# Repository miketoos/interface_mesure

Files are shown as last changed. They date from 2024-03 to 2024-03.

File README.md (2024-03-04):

# Projet d'Interface de Mesure pour Calculateur de Voiture

Ce projet vise à développer une interface de mesure entre un calculateur de voiture et l'être humain. L'objectif principal est de gérer jusqu'à 4 signaux d'injection pour une première carte, tandis que pour une deuxième carte, l'interface doit gérer les signaux de PMH (Point Mort Haut), l'écart en degré sur l'avance à l'allumage, le temps de conduction et la valeur d'accélération.

## Configuration du Projet
### Matériel Requis
- Accès à un calculateur de voiture (Clio 2)
- Carte électronique Arduino
- Sonde de programmation JLink
- Port USB B pour le téléversement du code

### Installation des Pilotes
1. Ajoutez la carte via le lien : [https://www.mattairtech.com/software/arduino/package_MattairTech_index.json](https://www.mattairtech.com/software/arduino/package_MattairTech_index.json)
2. Installez la carte via Outils / Type de carte / Gestionnaire de carte
3. Recherchez "MattairTech SAMD|L|C core for Arduino" et installez-le

### Programmation de la Carte
1. Sélectionnez la carte dans Arduino : Outils / Type de carte / "MattairTech MT-D21E(rev B)"
2. Sélectionnez l'oscillateur interne et le port de communication

### Blink (Test de Programmation)
- Assurez-vous que la carte est détectée dans le logiciel Arduino
- Chargez le programme Blink pour tester la programmation

## Fonctionnalités Principales
### Injection
- Contrôle jusqu'à 4 signaux d'injection pour la première carte (à compléter)

### Régime Moteur
- Mesure et affichage du régime moteur en tr/min

### Avance à l'Allumage
- Calcul et contrôle de l'avance à l'allumage en degrés

### Temps de Conduction
- Mesure du temps de conduction du moteur

### Accélération
- Calcul de l'accélération en fonction du régime moteur

## Production et Commande
- Les fichiers Gerber dans la section hardware permettent la production de cartes électroniques. Les entreprises peuvent être contactées en fournissant ces fichiers.
- Les fichiers de la section mécanique facilitent la production de boîtiers pour les cartes électroniques.

## Téléversement du Code
- Les codes nécessaires sont disponibles dans la section software.
- Utilisez une connectique en port USB B pour téléverser le code sur la carte.

## Contribuer
1. Fork le projet
2. Créez une branche pour votre fonctionnalité (`git checkout -b fonctionnalite/nouvelle-fonction`)
3. Committez vos changements (`git commit -m 'Ajout de nouvelle fonctionnalité'`)
4. Push vers la branche (`git push origin fonctionnalite/nouvelle-fonction`)
5. Créez une Pull Request

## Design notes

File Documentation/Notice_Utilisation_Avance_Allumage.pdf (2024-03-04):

# Notice Utilisation Carte Retard Allumage CIFAM

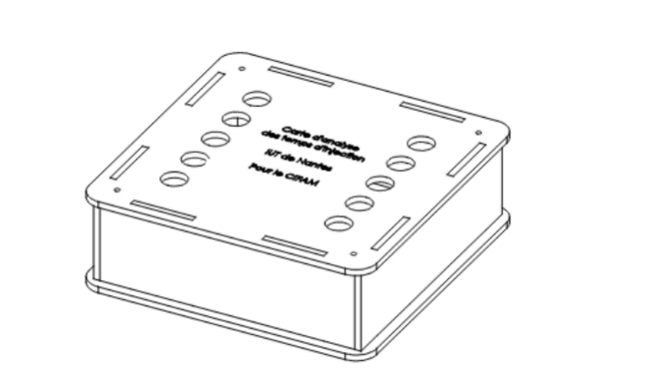
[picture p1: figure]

La carte Retard Allumage CIFAM est une carte qui permet de réaliser plusieurs calculs : Le Régime moteur ( Tr / min ), l’avance à l’allumage ( ° ), la durée de la charge de la bobine ou Temps de conduction ( ms ) et le calcul de l’accélération ( Tr / min²). Le gain de conversion est réglé en interne ( Tableau de conversion en annexe ) pour limiter le nombre de composants extérieurs. Les entrées et les sorties sont référencées à la masse. La consommation maximale est de 2.5W avec une alimentation de 5V, ce qui fait que cette carte est idéale pour un branchement sur batterie.

## Branchement :

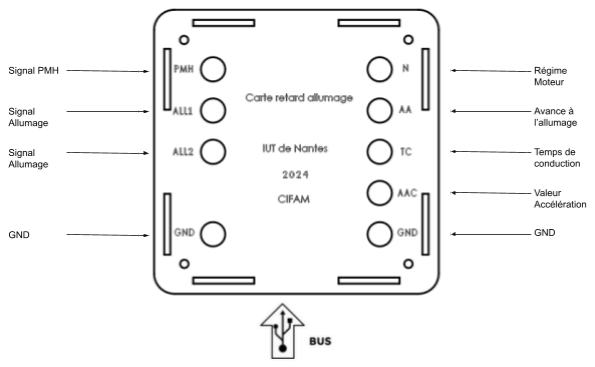
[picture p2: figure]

## Renseignement Techniques

Tension d’entrée ( Vbus ) | 5V
Courant d'entrée Max ( Ibus ) | 500 mA
Puissance Max ( P ) | 2,5 W
Tension d’entrée ( Vin ) | 0V - 5V
Tension de sortie ( Vout ) | 0V - 4.096V

## Description

FR
La carte électronique doit être alimentée sous 5V en courant continu (DC) sur le connecteur USB-B. Les dispositifs d’entrées sont en 0-5V; Les dispositifs de sortie sont en 0 - 4.096V, l’ensemble des dispositifs ne doit pas dépasser 2.5W. Les dispositifs d’entrée et de sortie sont référencés sur une masse commune (plan de masse). La carte est munie d’un bouton RESET qui permet de relancer le microcontrôleur de la carte. Une Led Rouge permet de savoir si la carte est sous tension. Une Led Verte permet de savoir si le microcontrôleur fonctionne.

Attention: Un branchement des dispositifs d’entrée avant la tension d’alimentation peut le rendre défectueux voire inutilisable

EN
The electronic board must be supplied with 5V direct current (DC) via the USB-B connector. Input devices are 0-5V; output devices are 0 - 4.096V, all devices must not exceed 2.5W. Input and output devices are referenced to a common ground (ground plane). The board is fitted with a RESET button to restart the board's microcontroller. A red LED indicates that the board is powered up. A green LED indicates that the microcontroller is working.

Caution: Connecting input devices before the supply voltage is applied may render them defective or even unusable.

## Tableau de conversion :

Sortie | Régime Moteur | Avance Allumage | Temps de conduction | Accélération
Unité | Tr / min | ° | ms | Tr / min
Echelle | 1V -> 1000 Tr / min | 68 mV - > 1° | 1V -> 1ms | 1V -> 1000 Tr /min² La valeur nulle est initialisée à 1V

## Remarque :

La carte ne peut sortir que 4.096V en sortie en raison du Convertisseur Analogique Numérique ( CAN ) situé sur le circuit, En fonction des valeurs souhaitées la modification en interne au niveau de programmation est possible afin de modifier les valeurs de sortie. Pour une modification du gain, il faudra passer par la modification du programme, et modifier les variables Gain_OutX. ( X étant le numéro de la sortie ).

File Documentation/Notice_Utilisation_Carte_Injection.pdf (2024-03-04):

# Notice Utilisation Carte Injection CIFAM

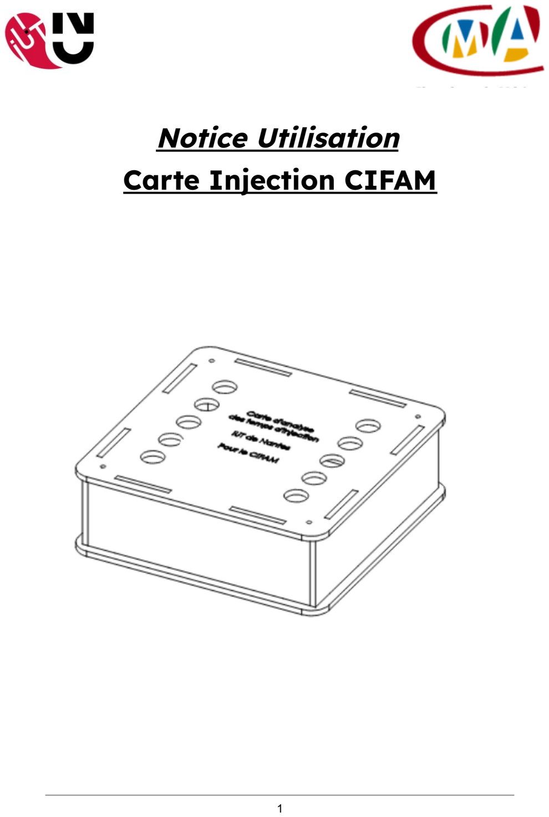
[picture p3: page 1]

La carte injection CIFAM est une carte qui permet de calculer le temps d’injection dans un moteur. Le gain de conversion est réglé en interne ( 1 ms -> 0,5V ) pour limiter le nombre de composants extérieurs. Les entrées et les sorties sont référencées à la masse. La consommation maximale est de 2.5W avec une alimentation de 5V, ce qui fait que cette carte est idéale pour un branchement sur batterie.

## Pin configuration

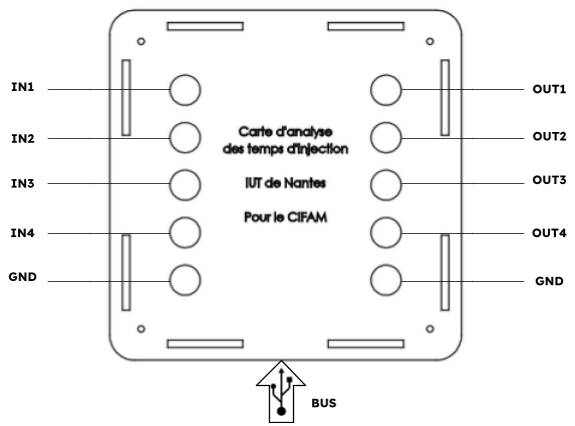
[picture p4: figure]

Renseignements Techniques

Tension d’entrée ( Vbus ) | 5V
Courant d'entrée Max ( Ibus ) | 500 mA
Puissance Max ( P ) | 2,5 W
Tension d’entrée ( Vin ) | 0V - 12V
Tension de sortie ( Vout ) | 0V - 4.96V

Masse commune ( GND )

## Description :

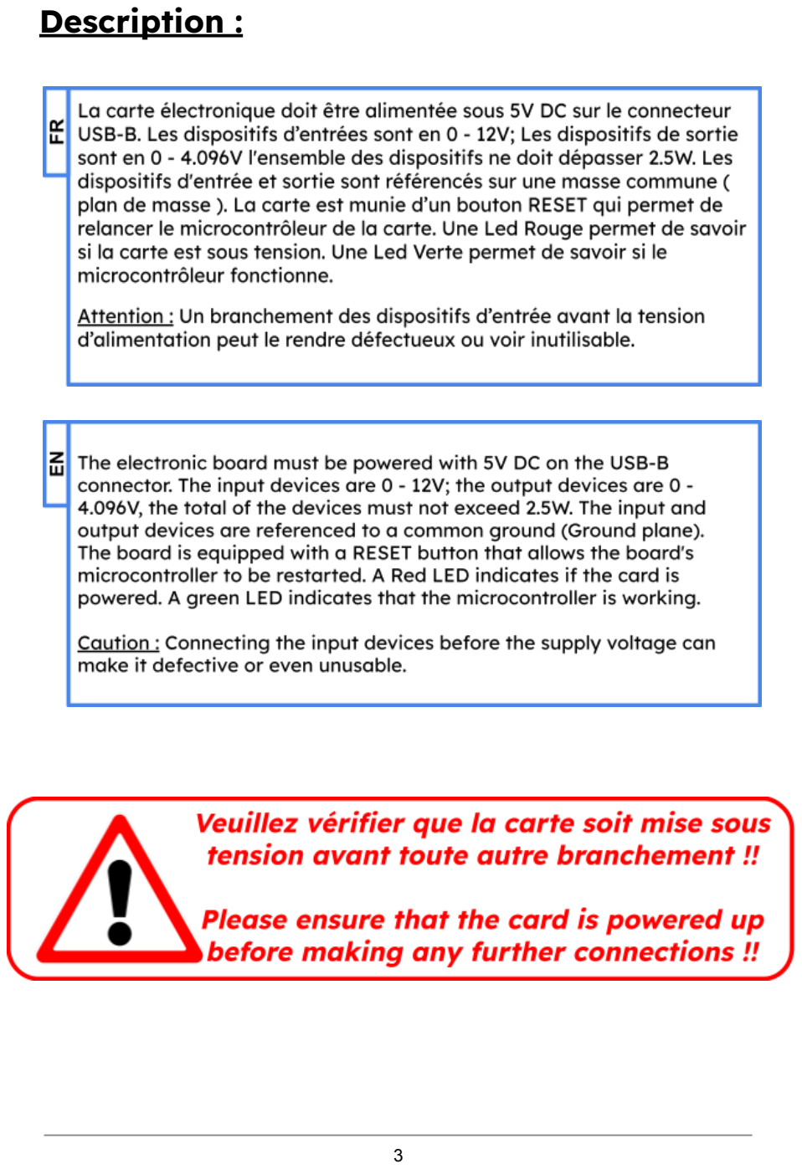
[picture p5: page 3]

## Application :

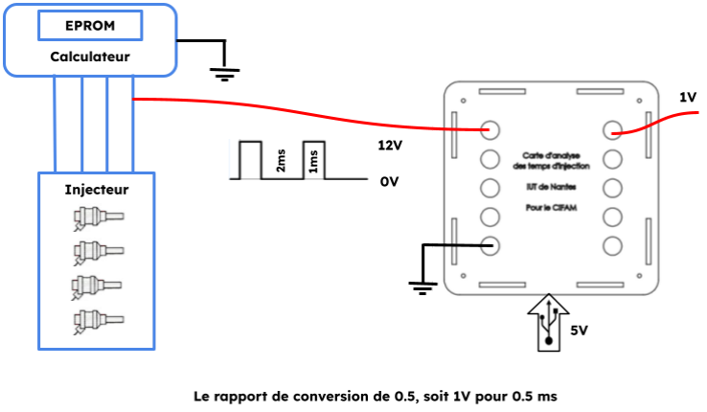
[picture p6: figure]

## Remarque :

La carte ne peut sortir que 4.096V en sortie en raison du Convertisseur Analogique Numérique ( CAN ) situé sur le circuit, soit la carte ne peut calculer au-delà de 8,192ms de temps d’injection. Pour une modification du gain, il faudra passer par la modification du programme, et modifier la variable GAIN.

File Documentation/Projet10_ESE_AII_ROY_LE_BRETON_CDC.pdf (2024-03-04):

RAPPORT SAE 6

# Interface de mesure pour calculateur automobile

Auteurs : Cyrian LE BRETON & Gaëtan ROY

Référence | Compte-rendu SAE 6
Titre du projet | Étude et réalisation du projet Interface de mesure
Type de projet | Électronique et informatique
Période du projet | 15/01/2024 - 19/01/2024
Nature du rapport | Livrable 1

## Sommaire

## État d’avancement du projet

L’intitulé de notre projet est “interface de mesure”, il consiste sommairement à rendre intelligible des signaux que génère un calculateur du moteur d’une voiture, pour être interprétable par un humain. Pour entrer plus dans le détail, il faut savoir que notre projet a été commencé lors de la SAE5 en septembre 2023 - décembre 2024, mais la première approche de ce projet date de 2017. Nous reprenons ainsi les cartes de mesures réalisées, voici un aperçu de la carte de retard à l'allumage.

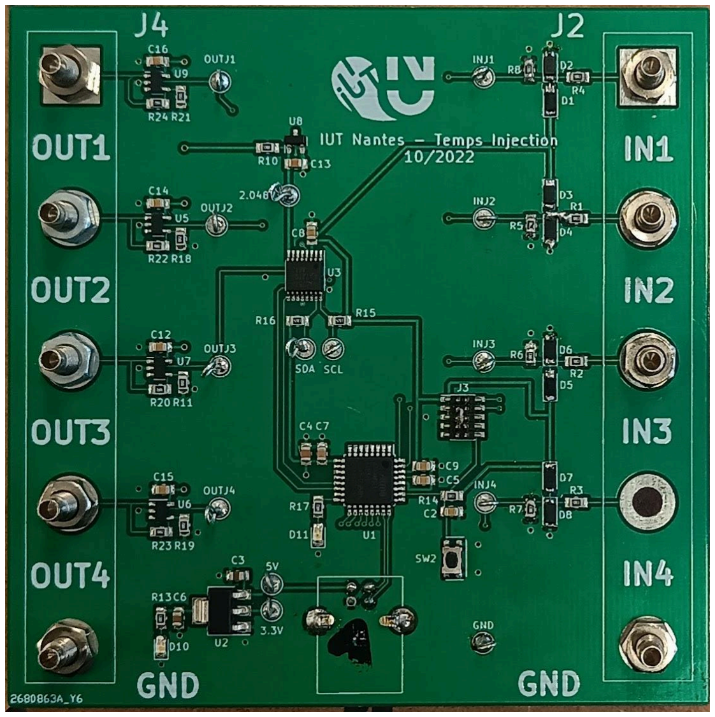
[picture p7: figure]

Puis de traiter les signaux dans la carte grâce à la programmation d’un microcontrôleur qui est une sorte de petit ordinateur intégré qui gère et contrôle les signaux électriques dans un dispositif électronique, grâce à un programme préalablement chargé. À la suite de ce traitement, nous sortons un certain niveau de tension qui donne des informations beaucoup plus claires pour l’utilisateur, lui évitant de faire des calculs, qui sont en fait assurés par le microcontrôleur, par exemple, on va faire en sorte que si on calcule que le moteur tourne actuellement à 1000 tours/min, on sorte 1V.

Donc comme rappelé, le projet débuté depuis 2017, depuis lors, la carte électronique a été désigné et produire, a été réalisée un boitier pour sécuriser l’ensemble et donner un aspect présentable, car l’objectif final est de “livrer” ce produit au CIFAM (CFA de la chambre de Métiers et de L’artisanat de Loire-Atlantique) pour leurs étudiants en mécanique. À ce titre, nous travaillons avec un de leur enseignant, Mr. Fourmy pour premièrement bien définir le cahier des charges et avoir un interlocuteur pour tester notre solution sur place, car c’est bien là-bas que nos cartes vont servir.

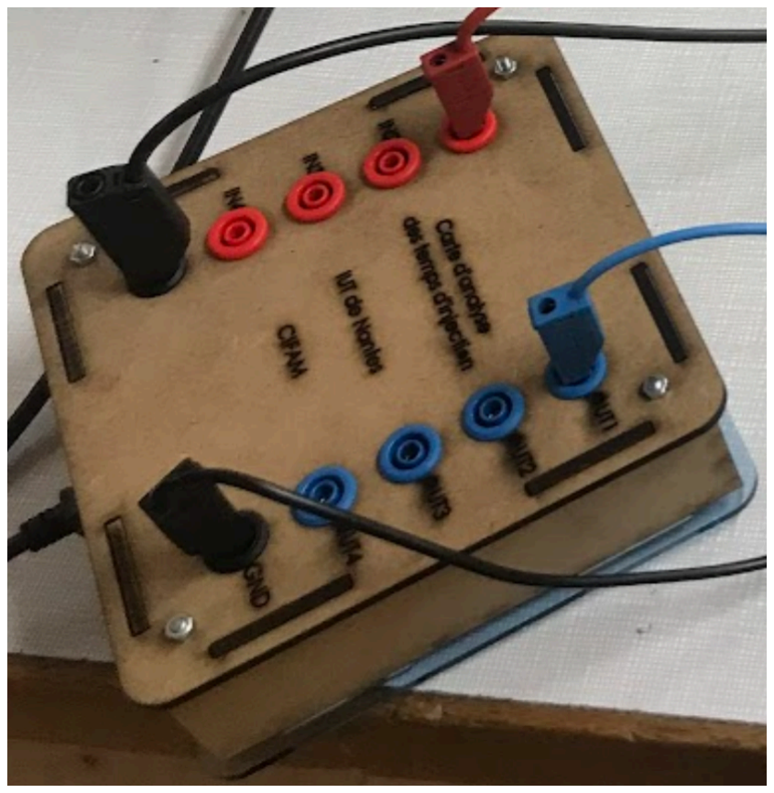
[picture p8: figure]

Ensuite, a été géré le calcul et la transmission de la durée du signal d’injection, qui est le moment où de l’essence est injectée dans un mélange air+essence, qui va ensuite être explosé pour assurer la rotation du moteur (qu’on appelle donc moteur à combustion et explosion).

Il reste à notre charge de traiter et programmer la gestion du signal de PMH (ou Point Mort Haut, qui représente le moment où le piston d'un moteur à combustion interne atteint sa position la plus haute dans le cylindre), ce qui nous permet de savoir quand le cylindre a effectué tout un cycle de rotation, et donc savoir le nombre de tours par minutes, qui nous affichons en sortie. Par ailleurs, en lien avec ce Point Mort Haut, nous traitons l’Avance à l’allumage qui moment précis où l'étincelle d'allumage est générée, et donc le moment où le mélange air+essence évoqué précédemment explose.
On l’appelle avance à l’allumage, car il a lieu un peu avant que le cylindre soit dans sa position la plus haute (donc au PMH que nous traitons auparavant) pour que la combustion se propage uniformément, assurant ainsi une libération maximale d'énergie au moment où le piston commence sa descente.

Voici comment sont schématisés tous ces signaux :

PHOTO DES SIGNAUX À TRAITER QU’ON A RETRAVAILLÉ (LE SCHÉMA)

On observe sur les signaux le calcul du PMH pour obtenir le régime moteur et le calcul avec le signal d’avance en plus, pour obtenir l’avance à l'allumage.

Pour l’heure, nous avons traité l’affichage du régime moteur (ses tours par minutes) et nous obtenons le signal de l’avance à l’allumage que nous affichons en simultanée avec le PMH.

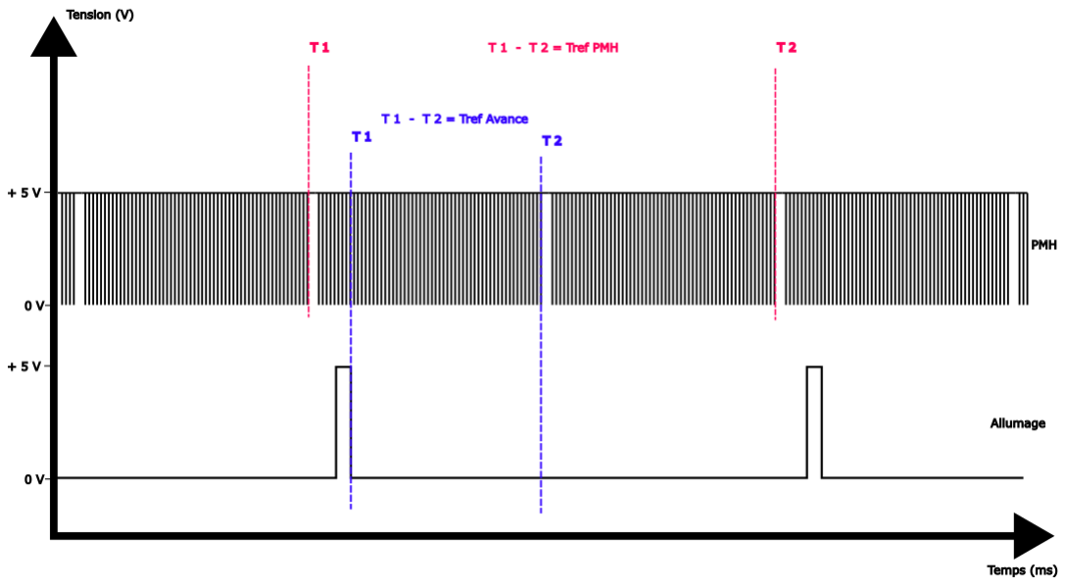
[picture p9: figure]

On est en phase de traitement et modification du code pour les calculs obtenus, car ils ne sont pas toujours cohérents.

## Indicateurs de performance (KPI) et protocole d’évaluation

## Indicateurs de performances

Originellement adaptée pour des signaux d’entrée de 0 à 12v et maintenant pour un signal de 0 à 5V seulement pour la carte de retard à l'allumage.

Seuil de sécurité :
- On mesure le niveau de tension
- En sorties des ponts diviseurs de tension des différentes entrées de la carte
- Il faut que la tension qui sorte des diodes soit exploitables par le microcontrôleur, donc il faut qu’il soit autour de 3.3 V avec 1V de tolérance
- On le contrôle avant chaque début de séance de test

Conformité :
- On mesure un niveau de tension
- Sur les différentes sorties de la carte
- On tolère que c’est acceptable quand la tension en sortie varie de +/- 10% par rapport à ce que l’on avait attendu
- On le mesure donc à chaque fois que l’on teste les sorties de la carte

Continuité des mesures :
- On mesure un niveau de tension
- Sur les différentes sorties de la carte
- On observe qu’il n’y ait pas de chutes aux subites montées de tension en sorties qui feraient dire que l’on a loupé une mesure ou un calcul essentiel à la sortie de celle-ci

## Fiches de test ou indicateur de performance

Seuil de sécurité
Mettre sous tension la carte et brancher les signaux de PMH et d’Avance à l’allumage | /
Mesurer les valeurs de tensions à l’aide de test Points | Observer une valeur valant 0 ou 3.3V

Conformité
Mettre sous tension la carte et brancher les signaux de PMH et d’Avance à l’allumage | /
Observer la sortie à l’aide d’un oscilloscope au laboratoire | Avoir 1V pour 1000 tour/min et 1v pour une avance à l’allumage de 10°
De même avec l’acquisition au CIFAM | De même

Continuité des mesures
Mettre sous tension la carte et brancher les signaux de PMH et d’Avance à l’allumage
Observer la sortie à l’aide d’un oscilloscope au laboratoire | Observer si les valeurs de sorties ne font des bons
De même avec l’acquisition au CIFAM | De même

## Résumé en anglais

During the first semester, we initiated the project involving the development of an interface for measuring automotive engine parameters. We've been working closely with Mr. Fourmy, our client at CIFAM, to meet specific project expectations. Our strategy involves building upon previous projects, utilizing the existing board to capture engine signals. We are expanding the scope by implementing various coding schemes in the microprocessor. This allows us to obtain diverse inputs from the car engine calculator, perform distinct calculations, and produce the desired outputs.

In summary, our primary objective was to finalize the software component of the second board, responsible for calculating engine speed and ignition timing advance. Additionally, we planned to design an enclosure to secure all the boards, ensuring a user-friendly appearance for students, and to create comprehensive documentation for their use.

Our project involves the creation of a signal processing board, serving as a measurement platform. The input to this platform is the output from a car engine calculator, which we convert into voltage levels for human interpretation. Cars require various calculations, such as fuel injection, ignition timing, and the top dead center, which refers to the highest position in the cylinder. We analyze these calculations, represented as signals, using an electronic card.

The stabilized measurements include fuel injection and top dead center, while the measurement of ignition advance currently in the process of being finalized. To assess our performance, we defined three key performance indicators: the "safety threshold" checks if the voltage reaching the microcontroller is exploitable; "conformity" assesses if the voltage level aligns with real observations and calculations; and "continuity of measurements" ensures that the output voltage remains stable without significant shifts.

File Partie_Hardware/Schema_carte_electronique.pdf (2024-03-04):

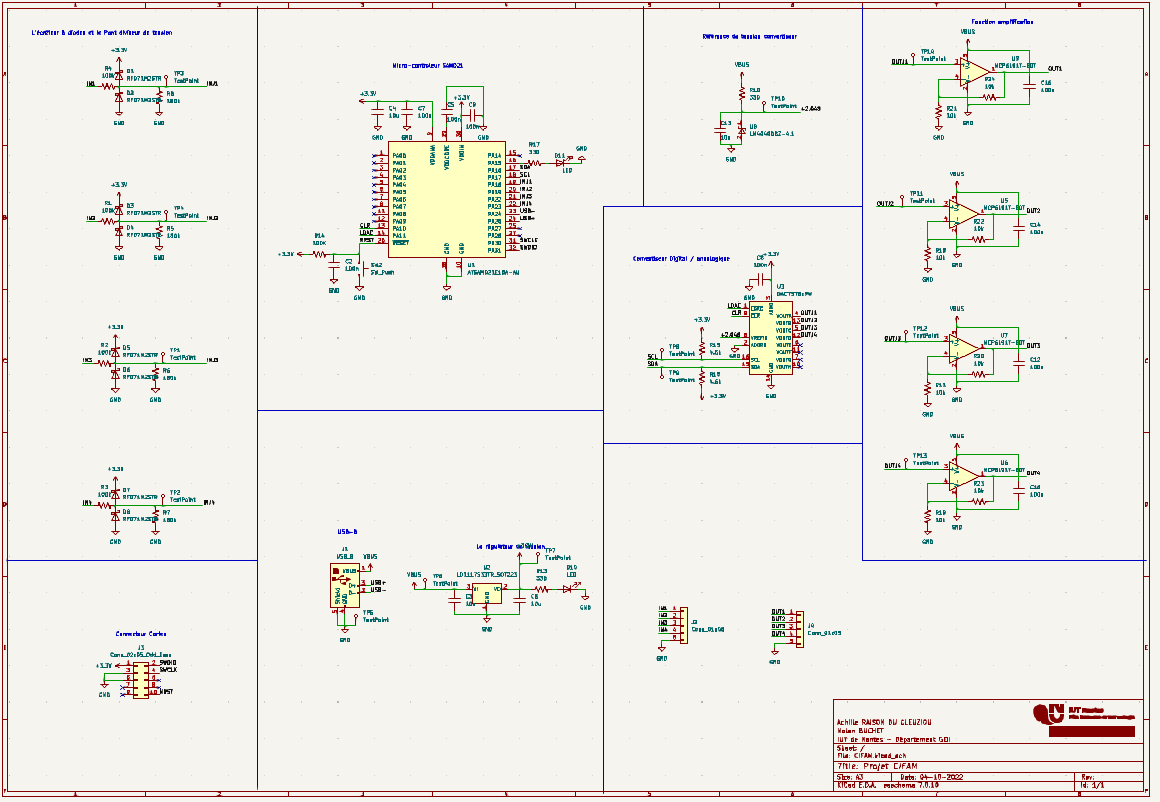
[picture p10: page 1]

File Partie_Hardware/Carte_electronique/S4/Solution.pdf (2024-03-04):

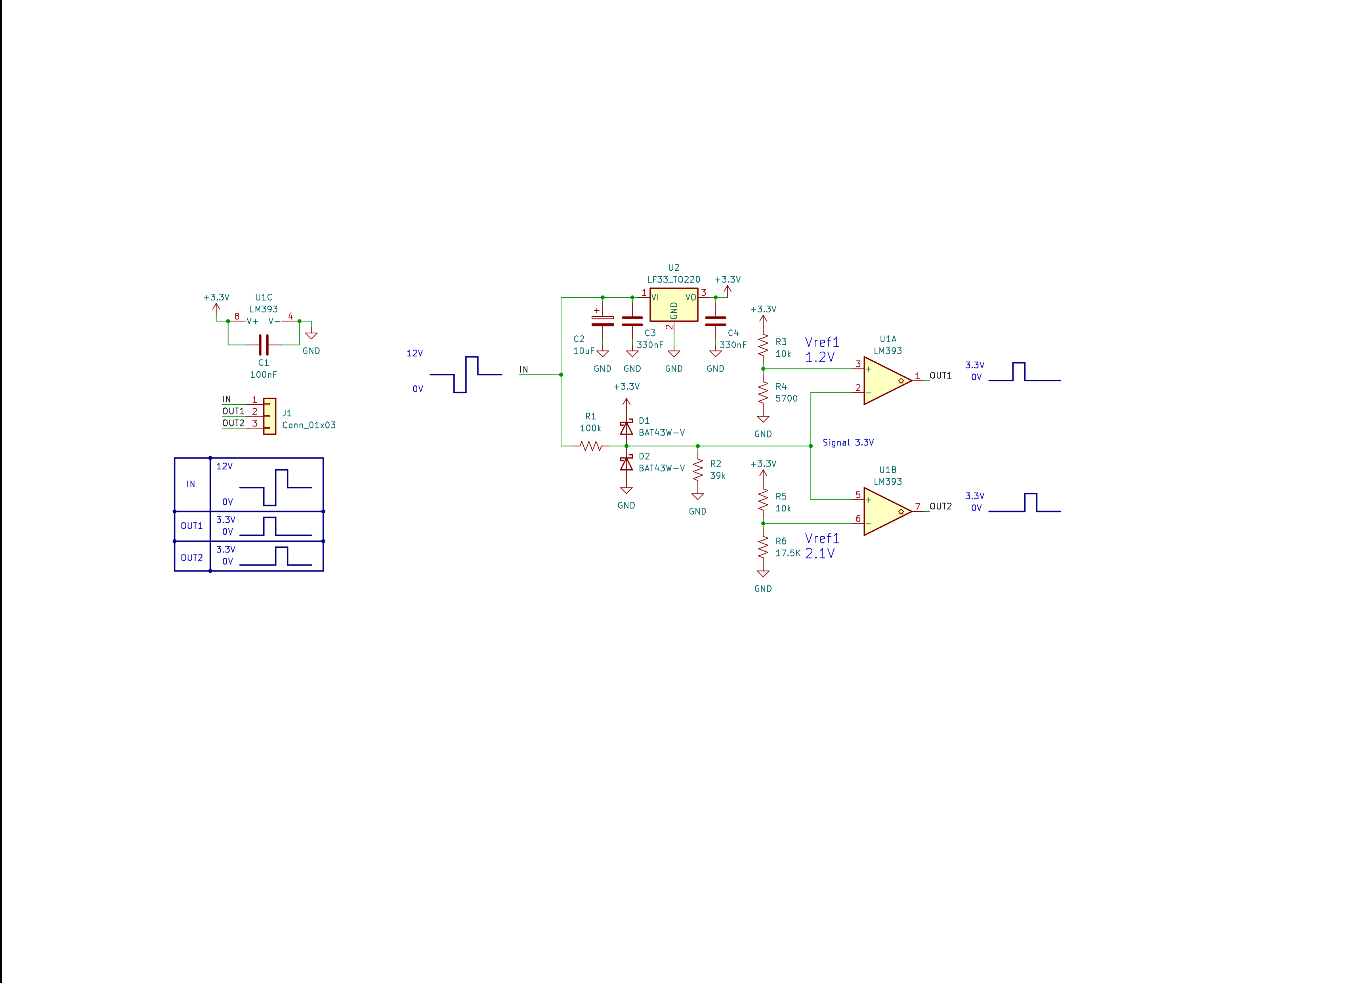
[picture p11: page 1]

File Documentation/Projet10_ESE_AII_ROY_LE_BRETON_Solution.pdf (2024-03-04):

RAPPORT SAE 6

# Interface de mesure pour calculateur automobile

Auteurs : Cyrian LE BRETON & Gaëtan ROY

Référence | Compte-rendu SAE 6
Titre du projet | Étude et réalisation du projet Interface de mesure
Type de projet | Électronique et informatique
Période du projet | 15/01/2024 - 19/01/2024
Nature du rapport | Livrable 2 - Recherche des solutions

## Sommaire

# Introduction et état d’avancement

Lors du précédent livrable, nous vous avions présenté le projet, ses objectifs et son état actuel. Pour résumer, nous devons programmer une carte électronique afin de faire une interface entre un calculateur de voiture et l'être humain.
Nous étions plus spécifiquement dédiés à la gestion des signaux de PMH (point mort haut) et d’écart en degré sur l’avance à l’allumage (qui est le moment précis où l’étincelle d’allumage est générée dans le moteur).
Depuis lors, nous avons bien programmé la sortie de l’avance à l’allumage, et nous nous sommes attaqués à transmettre le temps de conduction qui, dans le contexte des moteurs à combustion interne, se réfère à la durée pendant laquelle l'injecteur de carburant reste ouvert, permettant ainsi l'écoulement du carburant vers la chambre de combustion. Plus schématiquement, ça va être la durée du signal à l'état haut qui sort de notre capteur d’avance à l'allumage :

SCHÉMA COMME DANS LE PRÉCÉDENT LIVRABLE

Et l'accélération qui va être calculée en prenant deux valeurs de régime moteur, puis en comparant leurs différences par rapport au temps écoulé.

# Définition des pistes

En fait depuis le dernier livrable, nous avons réussi à faire l’avance à l’allumage qui comportait la principale problématique que nous présentons ci-dessus, c’est pour cela que nous avons choisi de tout de même faire une partie définition des pistes.

Problématique 1 : Nous devons faire en sorte qu’on puisse écrire sur 2 sorties en même temps.

Le problème vient du fait que l’on doit scruter en permanence l’état des signaux de PMH et d’allumage afin de prendre des mesures temporelles. Dans le même temps, notre unique moyen de calcul est un microprocesseur sur notre carte électronique. Il faut savoir que dans l’informatique, tous les calculs passent par ce qu’on appelle un cœur, et dans notre ordinateur, il y en a plusieurs, pour effectuer plusieurs calculs simultanément. Et donc dans notre cas, un microprocesseur n’en possède qu’un seul. Ce qui veut dire que lorsque l'on est en train de lire une entrée ou d’effectuer un calcul, nous ne pouvons par exemple pas écrire en sortie en même temps.

Ce qui au final cause des comportements imprévus à cause de mesures manquées ou d’écriture interrompus. Le but est donc d’isoler l’écriture en sortie par rapport à la lecture des états.

Il faut aussi savoir que le fonctionnement central de notre programme sont les interruptions sur des entrées, c'est-à-dire qu’est scruté en permanence l’état d’une entrée et toute une série d'instructions est alors exécutée.

Pistes Envisagées :

1. Horloge Indépendante :

Une des premières solutions envisagées est de créer une nouvelle interruption, cette fois sur une horloge, autrement dit qu’au lieu de s’activer lorsqu’on a un état bas ou un état haut sur une entrée. Elle va s’activer tous les x temps indépendamment du reste.

L’idée est donc de faire les calculs de toutes les sorties comme effectué en temps normal, et d’écrire en sortie dans cette fameuse horloge.

2. Écriture en permanence :

Comme expliqué précédemment, les interruptions sont configurées sur les entrées et les calculs sont faits à ce moment-là.

L’idée de cette piste est d’écrire sur la sortie en permanence, l’avantage est qu’il n’y a pas à se soucier du moment où ça arrive, puisque l’écriture ne sera interrompue que par les interruptions.

3. Identification des Plages Inoccupées :

Il s’agit là d’étudier plus en profondeur le comportement des signaux que nous recevons (voir photo). Et de cibler les moments où il ne serait pas judicieux de mettre en place une interruption, car il n’y aura pas de signaux à analyser. Et donc d’utiliser ce temps gagné pour écrire en sortie.

Nous avons donc testé ces 3 pistes envisagées tour à tour afin de voir laquelle serait judicieuse.

# Choix de solution

- Le choix de la première solution a été assez infructueuse parce qu'il n’y avait pas de bonne réponse à la question quelle fréquence lui donner. Car la voiture n’a pas de comportement stable, le but même du projet est de pouvoir visualiser l’évolution du régime moteur, de l’avance à l’allumage dans le cas où la voiture accélère ou décélère. Donc la fréquence va évoluer et l'horloge configurée va entrer en conflit avec les signaux d’entrées qu’on veut observer. Car nous devons configurer l’horloge comme une interruption, ce qui veut dire qu’elle s'exécute jusqu’au bout sans tenir compte du reste, des mesures temporelles sont alors perdues.
Une solution serait de redéfinir en permanence l’horloge, mais cette solution se serait avérée trop complexe et trop coûteuse en ressource de calcul.
- Le choix de la deuxième solution a aussi été une impasse, en effet dans ce cas l’écriture ne rentre pas en conflit avec les mesures temporelles, car ce n’est pas une interruption. Mais dans ce cas, c'est donc bien l’écriture qui peut être interrompue. De plus, ce n’est pas une méthode très satisfaisante dans le sens où on transmet des infos au DAC en permanence alors qu’il suffit de lui transmettre une seule fois une certaine valeur à écrire pour qu’il le fasse jusqu'à un prochain changement.
- C’est donc la troisième solution qui va être retenue. Comme vous pouvez le voir sur le schéma, avec le front descendant de l’avance à l’allumage, il y a un temps certain avant d’avoir un nouveau signal PMH à exploiter, c’est donc à ce moment-là que nous avons choisi d’écrire les valeurs de tensions en sortie.

# Chiffrage

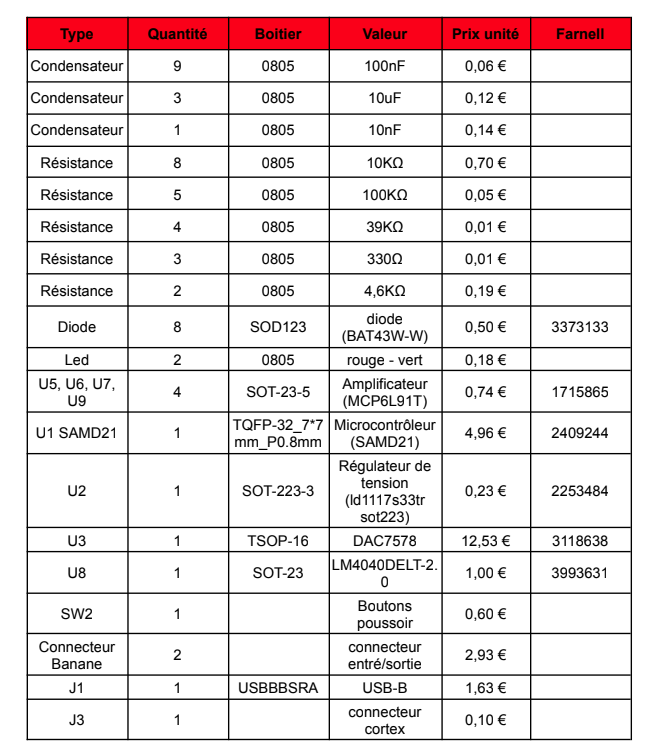
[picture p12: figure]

Total : 41.57 € par carte électronique, soit 166.28 au total pour les 4 cartes.

# Présentation d’un brevet

Brevet capteur point mort haut (PMH):

Dans notre apport au projet, notre composante centrale est de gérer les signaux issus du capteur PMH, plus spécifiquement d’une voiture à combustion interne.

https://data.inpi.fr/brevets/FR3042001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

De même pour le capteur injection :

https://data.inpi.fr/brevets/EP1731743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 4070184 (https://data.inpi.fr/brevets/WO2004070184?q=capteur%20injection%20combustion#WO2004070184)

Enfin, le DAC nous permet d’écrire une tension en sortie, ce qui est tout l’intérêt de notre projet :
https://data.inpi.fr/brevets/WO2011016969?q=convertisseur%20analogique%20num%C3%A 9rique#WO2011016969 (https://data.inpi.fr/brevets/WO2011016969?q=convertisseur%20analogique%20num%C3%A9rique#WO2011016969)

# Décomposition et Diagramme de Gantt

https://docs.google.com/spreadsheets/d/1YVHl-ruIdva_ABZV49TbMsDJOpPbtX4b/edit#gid=552497546 (https://docs.google.com/spreadsheets/d/1YVHl-ruIdva_ABZV49TbMsDJOpPbtX4b/edit#gid=552497546)

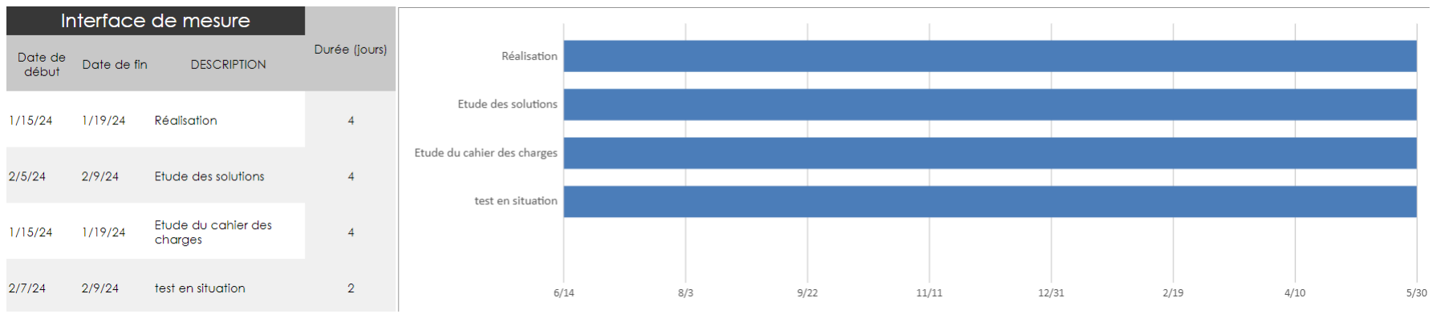
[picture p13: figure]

# Résumé en Anglais

Introduction and Progress Update:

In the previous deliverable, we introduced the project's objectives and outlined its current status. Our primary goal is to program an electronic card that serves as a crucial interface between a car's computer and the human user. Specifically, our focus has been on managing signals related to Top Dead Center (PMH) and the degree deviation in ignition advance. Notably, we have successfully programmed the ignition advance output and shifted our attention to transmitting the fuel injector's conduction time, a critical aspect in internal combustion engines.

Definition of Tracks and Challenges:

Since the last update, we encountered a significant challenge – the need to write to two outputs simultaneously. This challenge arises from the constant monitoring of PMH and ignition signals for timely measurements while utilizing a single-core microprocessor for all calculations. The core issue is the potential for unexpected behaviors due to missed measurements or interrupted writing during simultaneous input reading and output writing. To address this, we explored three potential solutions: an independent clock, continuous writing, and identifying unused time intervals for output writing.

Choice of Solution and Cost Estimation:

After thorough evaluation, the first solution involving an independent clock proved challenging due to the variable behavior of the vehicle, making frequency calibration problematic. The second solution, continuous writing, faced impracticality as it allowed interruptions, risking data loss. Ultimately, we chose the third solution, identifying unused intervals for output writing, capitalizing on the time gap between ignition advance signals. The cost estimation for implementing these solutions totals 166.28 € for four electronic cards, averaging 41.57 € per card.

Patent Contribution and Interface Decomposition:

Our project significantly contributes to the field through the management of signals from the Top Dead Center (PMH) sensor in internal combustion engine vehicles. Relevant patents for PMH sensors and fuel injection sensors were explored to enhance our understanding and implementation. To facilitate project management, a Gantt chart illustrating the decomposition of the measurement interface it is providing a visual roadmap for the upcoming phases.

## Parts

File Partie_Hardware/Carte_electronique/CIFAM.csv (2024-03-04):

# | Reference | Qty | Value | Footprint | DNP
1 | C2, C5, C7, C8, C9, C12, C14, C15, C16 | 9 | 100n | empreintes_iut:C_0805_2012Metric_Pad1.15x1.40mm_HandSolder
2 | C3, C4, C6 | 3 | 10u | empreintes_iut:C_0805_2012Metric_Pad1.15x1.40mm_HandSolder
3 | C13 | 1 | 10n | empreintes_iut:C_0805_2012Metric_Pad1.15x1.40mm_HandSolder
4 | D1, D2, D3, D4, D5, D6, D7, D8 | 8 | RF071M2STR | Diode_SMD:D_SOD-123
5 | D10, D11 | 2 | LED | LED_SMD:LED_0805_2012Metric_Pad1.15x1.40mm_HandSolder
6 | J1 | 1 | USB_B | EmpreinteCIFAM:USBBSRA
7 | J2, J4 | 2 | Conn_01x05 | modules:Connector_1x05_P2.54mm_Vertical
8 | J3 | 1 | Conn_02x05_Odd_Even | Connector_PinHeader_1.27mm:PinHeader_2x05_P1.27mm_Vertical_SMD
9 | R1, R2, R3, R4 | 4 | 100k | empreintes_iut:R_0805_2012Metric_Pad1.15x1.40mm_HandSolder
10 | R5, R6, R7, R8 | 4 | 180k | empreintes_iut:R_0805_2012Metric_Pad1.15x1.40mm_HandSolder
11 | R10, R13, R17 | 3 | 330 | empreintes_iut:R_0805_2012Metric_Pad1.15x1.40mm_HandSolder
12 | R11, R18, R19, R20, R21, R22, R23, R24 | 8 | 10k | empreintes_iut:R_0805_2012Metric_Pad1.15x1.40mm_HandSolder
13 | R14 | 1 | 100K | empreintes_iut:R_0805_2012Metric_Pad1.15x1.40mm_HandSolder
14 | R15, R16 | 2 | 4.6k | empreintes_iut:R_0805_2012Metric_Pad1.15x1.40mm_HandSolder
15 | SW2 | 1 | SW_Push | empreintes_iut:Switch_bouton
16 | TP1, TP2, TP3, TP4, TP5, TP6, TP7, TP8, TP9, TP10, TP11, TP12, TP13, TP14 | 14 | TestPoint | empreintes_iut:TestPoint-12
17 | U1 | 1 | ATSAMD21E18A-AU | Package_QFP:TQFP-32_7x7mm_P0.8mm
18 | U2 | 1 | LD1117S33TR_SOT223 | Package_TO_SOT_SMD:SOT-223-3_TabPin2
19 | U3 | 1 | DAC7578xPW | Package_SO:TSSOP-16_4.4x5mm_P0.65mm
20 | U5, U6, U7, U9 | 4 | MCP6L91T-EOT | Package_TO_SOT_SMD:SOT-23-5
21 | U8 | 1 | LM4040DBZ-4.1 | Package_TO_SOT_SMD:SOT-23

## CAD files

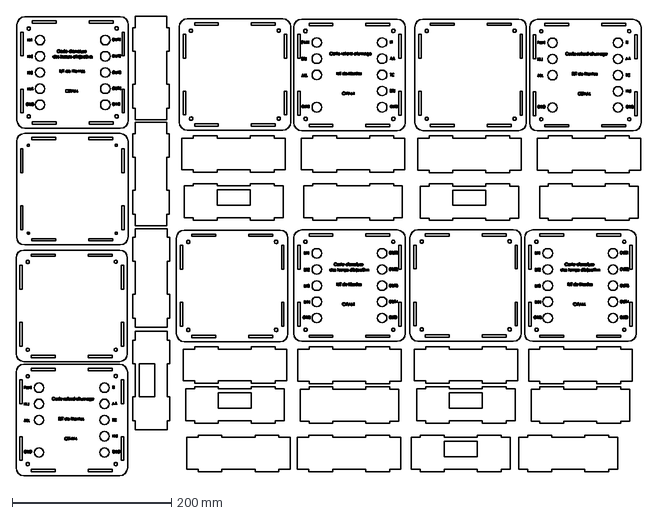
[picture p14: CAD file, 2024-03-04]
Partie_Mecanique/Plaque_de_800mm_sur_600mm.dxf
784.8 x 577.1 mm

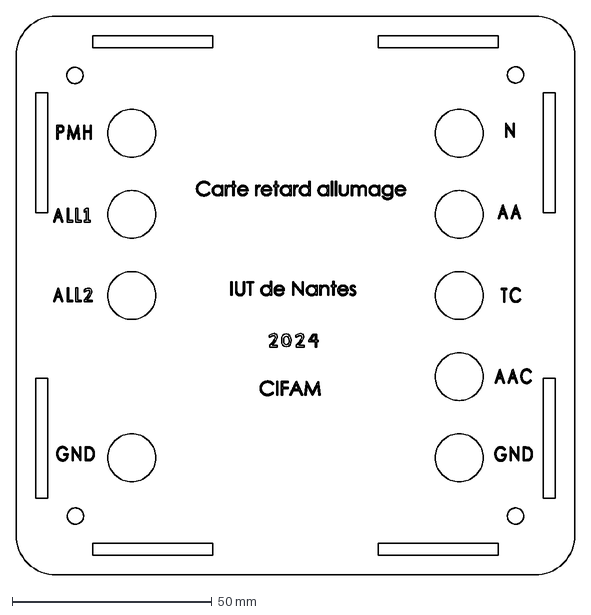
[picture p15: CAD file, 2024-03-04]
Partie_Mecanique/PMH_Avance_Allumage/haut_PMH_Avance_Allumage.dxf
140.0 x 140.0 mm

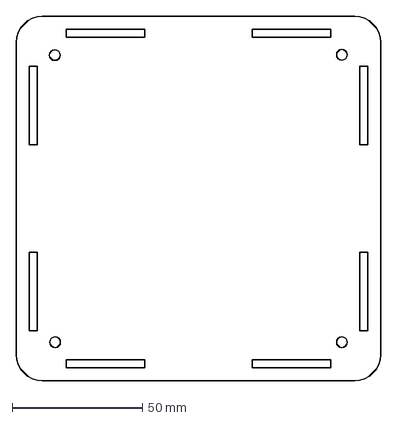
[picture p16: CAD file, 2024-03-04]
Partie_Mecanique/Temps_Injection/bas.DXF
140.0 x 140.0 mm

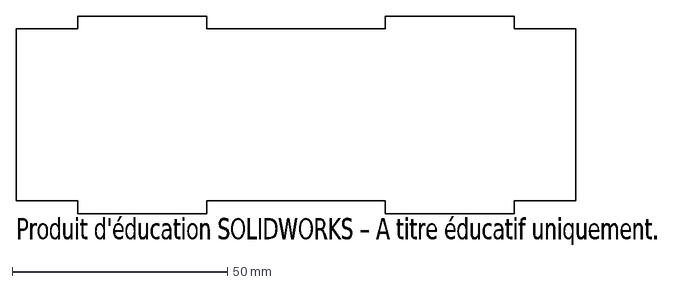
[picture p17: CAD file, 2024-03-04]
Partie_Mecanique/PMH_Avance_Allumage/coter.DXF
Produit d'éducation SOLIDWORKS – A titre éducatif uniquement.

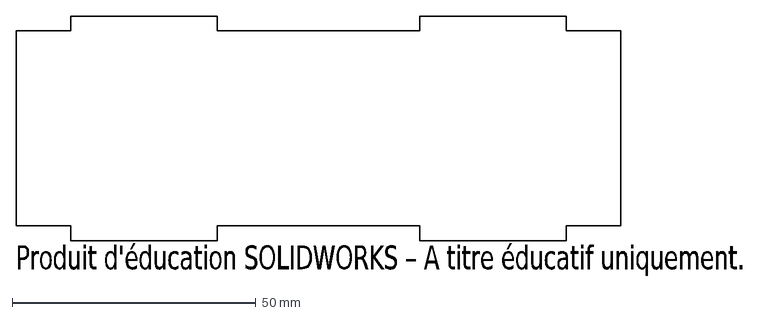
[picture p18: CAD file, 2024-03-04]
Partie_Mecanique/Temps_Injection/coterversuseUSB.DXF
Produit d'éducation SOLIDWORKS – A titre éducatif uniquement.

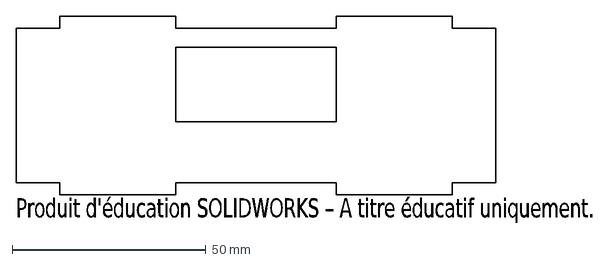
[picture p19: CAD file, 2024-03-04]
Partie_Mecanique/Temps_Injection/coterUSB.DXF
Produit d'éducation SOLIDWORKS – A titre éducatif uniquement.

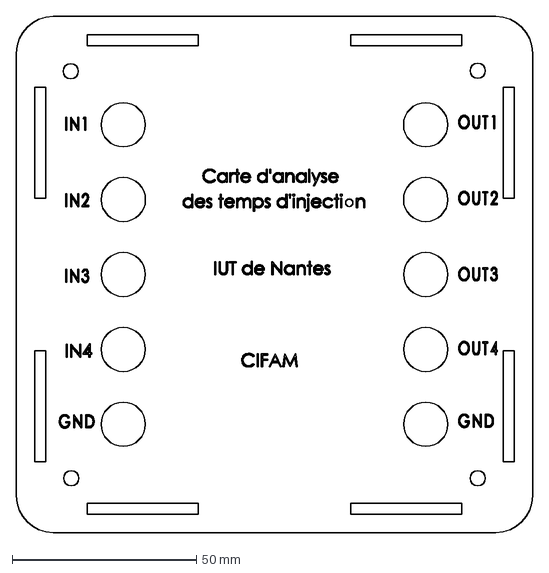
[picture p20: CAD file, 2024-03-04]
Partie_Mecanique/Temps_Injection/haut injection.DXF
140.0 x 140.0 mm

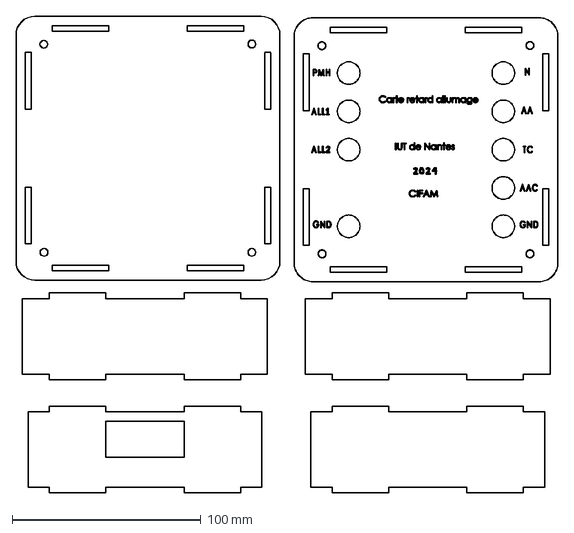
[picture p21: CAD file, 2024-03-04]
Partie_Mecanique/PMH_Avance_Allumage/Toutes_pieces_PMH_Avance_Allumage.dxf
287.5 x 252.8 mm

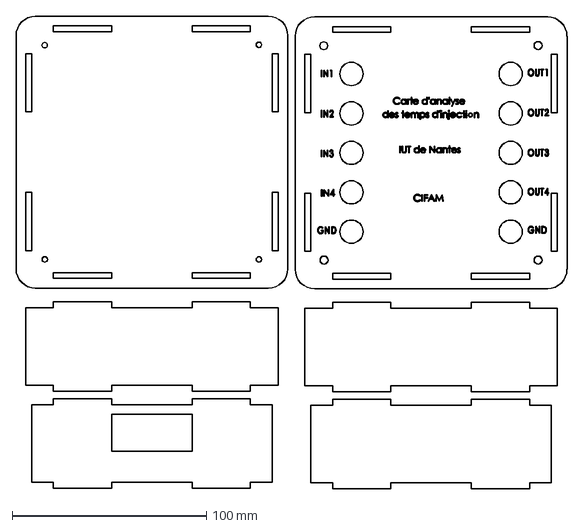
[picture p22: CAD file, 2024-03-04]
Partie_Mecanique/Temps_Injection/Toutes_pieces_temps_injection.dxf
283.7 x 243.3 mm

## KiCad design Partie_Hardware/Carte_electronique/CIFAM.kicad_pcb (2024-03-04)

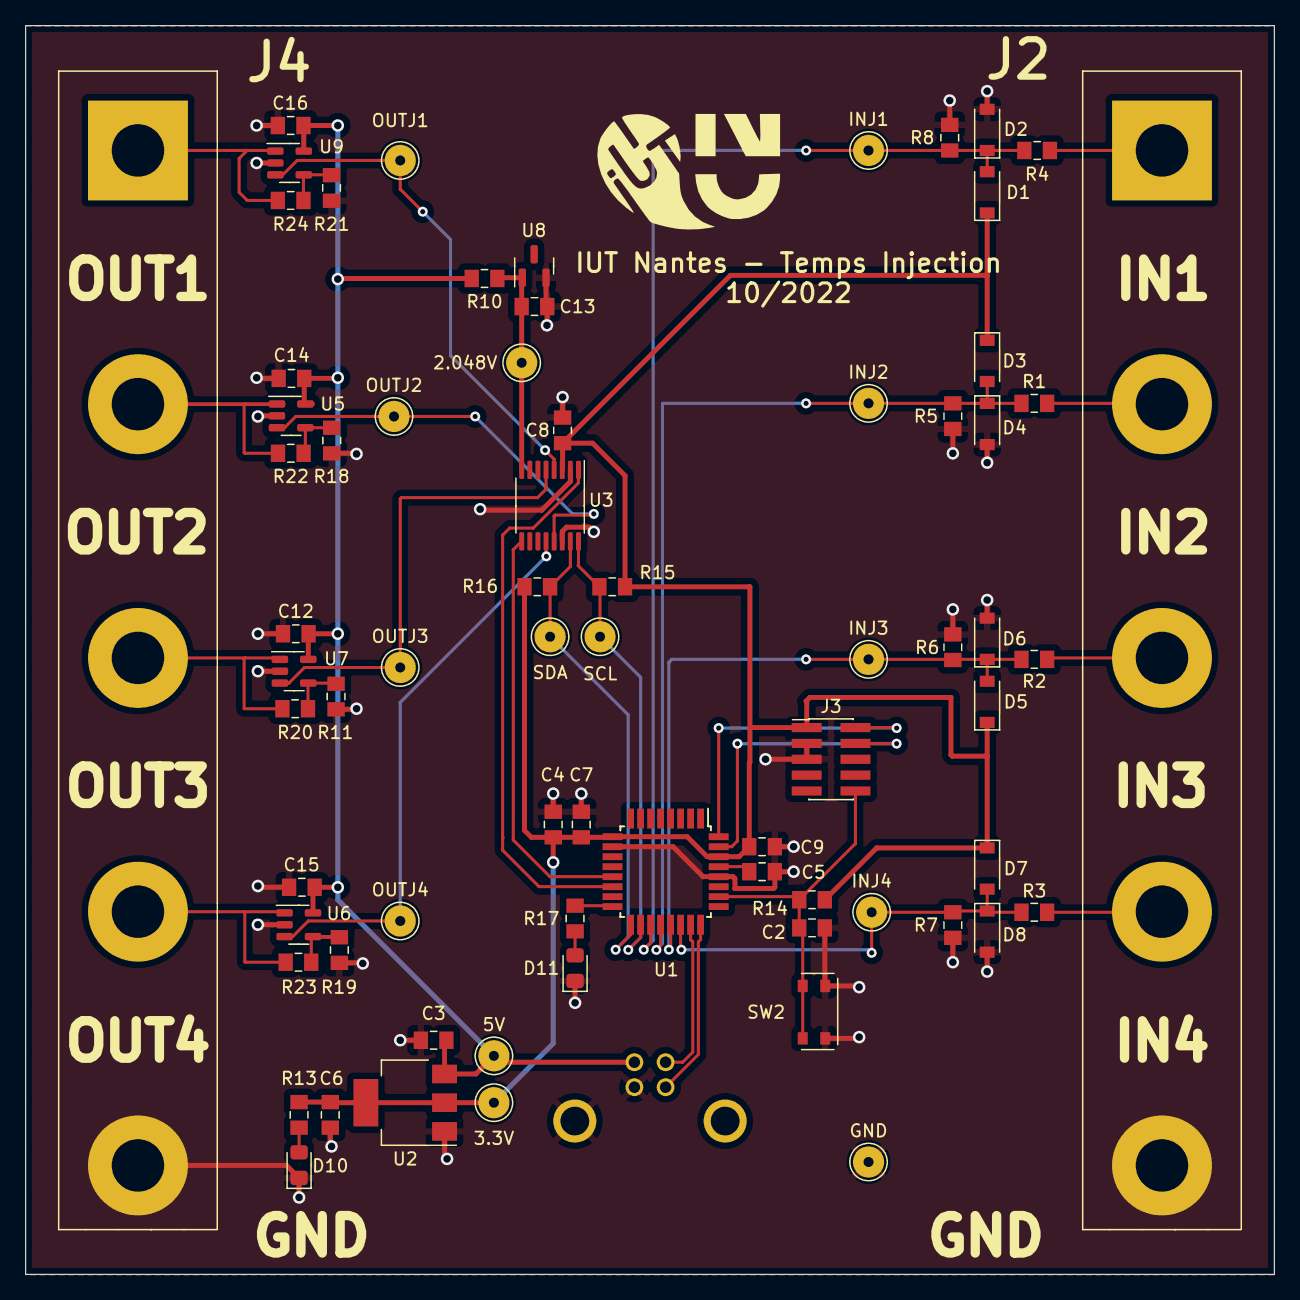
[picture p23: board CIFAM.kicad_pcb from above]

Board: 2 copper layers, 100.0 x 100.0 mm, 72 parts (0 on the bottom side), 37 nets.

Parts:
2.048V, 3.3V, 5V: TestPoint; TestPoint-12
C2, C5, C7, C8, C9, C12, C14, C15, C16: 100n; C_0805_2012Metric_Pad1.15x1.40mm_HandSolder
C3, C4, C6: 10u; C_0805_2012Metric_Pad1.15x1.40mm_HandSolder
C13: 10n; C_0805_2012Metric_Pad1.15x1.40mm_HandSolder
D1, D2, D3, D4, D5, D6, D7, D8: BAT43W-V; D_SOD-123
D10, D11: LED; LED_0805_2012Metric_Pad1.15x1.40mm_HandSolder
GND: TestPoint; TestPoint-12
INJ1, INJ2, INJ3, INJ4: TestPoint; TestPoint-12
J1: USB_B; USBBSRA
J2, J4: Conn_01x05; Connector_1x05_P2.54mm_Vertical
J3: Conn_02x05_Odd_Even; PinHeader_2x05_P1.27mm_Vertical_SMD
OUTJ1, OUTJ2, OUTJ3, OUTJ4: TestPoint; TestPoint-12
R1, R2, R3, R4: 100k; R_0805_2012Metric_Pad1.15x1.40mm_HandSolder
R5, R6, R7, R8: 39k; R_0805_2012Metric_Pad1.15x1.40mm_HandSolder
R10, R13, R17: 330; R_0805_2012Metric_Pad1.15x1.40mm_HandSolder
R11, R18, R19, R20, R21, R22, R23, R24: 10k; R_0805_2012Metric_Pad1.15x1.40mm_HandSolder
R14: 100K; R_0805_2012Metric_Pad1.15x1.40mm_HandSolder
R15, R16: 4.6k; R_0805_2012Metric_Pad1.15x1.40mm_HandSolder
SCL: TestPoint; TestPoint-12
SDA: TestPoint; TestPoint-12
SW2: SW_Push; Switch_bouton
U1: ATSAMD21E18A-AU; TQFP-32_7x7mm_P0.8mm
U2: LD1117S33TR_SOT223; SOT-223-3_TabPin2
U3: DAC7578xPW; TSSOP-16_4.4x5mm_P0.65mm
U5, U6, U7, U9: MCP6L91T-EOT; SOT-23-5
U8: LM4040DBZ-4.1; SOT-23

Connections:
+3.3V: 3.3V.1, C4.1, C6.1, C7.1, C8.2, C9.1, D1.1 (K), D3.1 (K), D5.1 (K), D7.1 (K), J3.1, R13.1, R14.1, R15.1, R16.2, U1.9 (VDDANA), U1.30 (VDDIN), U2.2 (VO), U3.3 (AVDD)
/+2.048: 2.048V.1, C13.1, R10.1, U3.8 (VREFIN), U8.1 (K)
/CLR: U1.13 (PA10), U3.9 (~CLR)
/IN1: J2.1, R4.1
/IN2: J2.2, R1.1
/IN3: J2.3, R2.1
/IN4: J2.4, R3.1
/INJ1: D1.2 (A), D2.1 (K), INJ1.1, R4.2, R8.1, U1.19 (PA18)
/INJ2: D3.2 (A), D4.1 (K), INJ2.1, R1.2, R5.1, U1.20 (PA19)
/INJ3: D5.2 (A), D6.1 (K), INJ3.1, R2.2, R6.1, U1.21 (PA22)
/INJ4: D7.2 (A), D8.1 (K), INJ4.1, R3.2, R7.1, U1.22 (PA23)
/LDAC: U1.14 (PA11), U3.1 (~LDAC)
/NRST: C2.1, J3.10, R14.2, SW2.1, U1.26 (~RESET)
/OUT1: J4.1, R24.2, U9.1
/OUT2: J4.2, R22.2, U5.1
/OUT3: J4.3, R20.2, U7.1
/OUT4: J4.4, R23.2, U6.1
/OUTJ1: OUTJ1.1, U3.4 (VOUTA), U9.3 (+)
/OUTJ2: OUTJ2.1, U3.13 (VOUTB), U5.3 (+)
/OUTJ3: OUTJ3.1, U3.5 (VOUTC), U7.3 (+)
/OUTJ4: OUTJ4.1, U3.12 (VOUTD), U6.3 (+)
/SCL: R15.2, SCL.1, U1.18 (PA17), U3.16 (SCL)
/SDA: R16.1, SDA.1, U1.17 (PA16), U3.15 (SDA)
/SWCLK: J3.4, U1.31 (PA30)
/SWDIO: J3.2, U1.32 (PA31)
/USB+: J1.3 (D+), U1.24 (PA25)
/USB-: J1.2 (D-), U1.23 (PA24)
GND: C2.2, C3.2, C4.2, C5.2, C6.2, C7.2, C8.1, C9.2, C12.2, C13.2, C14.2, C15.2, C16.2, D2.2 (A), D4.2 (A), D6.2 (A), D8.2 (A), D10.1 (K), D11.1 (K), GND.1, J1.4 (GND), J1.5 (Shield), J2.5, J3.3, J3.5, J4.5, R5.2, R6.2, R7.2, R8.2, R11.2, R18.2, R19.2, R21.2, SW2.2, U1.10 (GND), U1.28 (GND), U2.1 (GND), U3.2 (ADDR0), U3.14 (GND), U5.2 (V-), U6.2 (V-), U7.2 (V-), U8.2 (A), U9.2 (V-)
unnamed: C5.1, U1.29 (VDDCORE)
unnamed: D10.2 (A), R13.2
unnamed: D11.2 (A), R17.2
unnamed: R11.1, R20.1, U7.4 (-)
unnamed: R17.1, U1.16 (PA15)
unnamed: R18.1, R22.1, U5.4 (-)
unnamed: R19.1, R23.1, U6.4 (-)
unnamed: R21.1, R24.1, U9.4 (-)
VBUS: 5V.1, C3.1, C12.1, C14.1, C15.1, C16.1, J1.1 (VBUS), R10.2, U2.3 (VI), U5.5 (V+), U6.5 (V+), U7.5 (V+), U9.5 (V+)

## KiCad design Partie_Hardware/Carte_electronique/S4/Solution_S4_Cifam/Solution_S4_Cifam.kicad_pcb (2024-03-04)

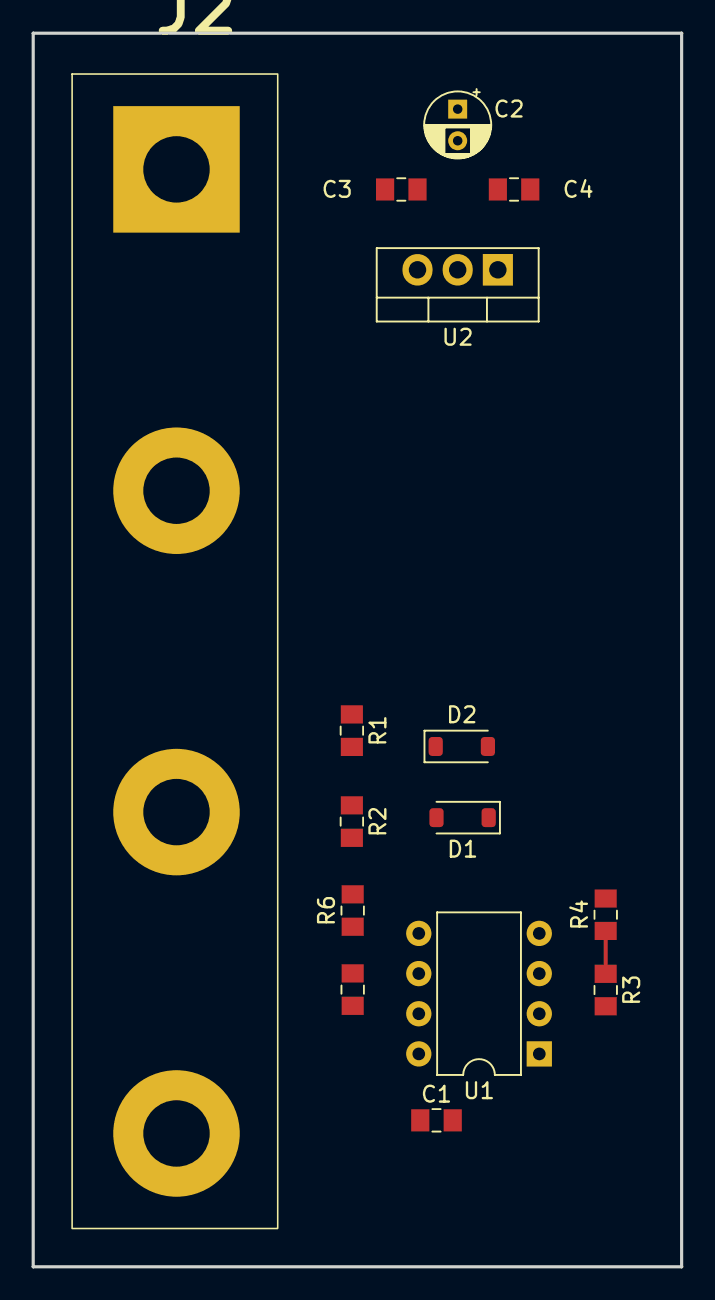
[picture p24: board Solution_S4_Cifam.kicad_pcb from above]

Board: 2 copper layers, 41.0 x 78.0 mm, 15 parts (0 on the bottom side), 8 nets.

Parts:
C1: 100nF; C_0805_2012Metric_Pad1.15x1.40mm_HandSolder
C2: 10uF; CP_Radial_D4.0mm_P2.00mm
C3, C4: 330nF; C_0805_2012Metric_Pad1.15x1.40mm_HandSolder
D1, D2: BAT43W-V; D_SOD-123
J2: Conn_01x04; Connector_1x04_P2.54mm_Vertical
R1: 100k; R_0805_2012Metric_Pad1.15x1.40mm_HandSolder
R2: 39k; R_0805_2012Metric_Pad1.15x1.40mm_HandSolder
R3, R5: 10k; R_0805_2012Metric_Pad1.15x1.40mm_HandSolder
R4: 5700; R_0805_2012Metric_Pad1.15x1.40mm_HandSolder
R6: 17.5K; R_0805_2012Metric_Pad1.15x1.40mm_HandSolder
U1: LM393; DIP-8_W7.62mm
U2: LF33_TO220; TO-220-3_Vertical

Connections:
+3.3V: C1.1, C4.2, D1.1 (K), R3.2, R5.2, U1.8 (V+), U2.3 (VO)
/IN: C2.1, C3.2, J2.1, R1.1, U2.1 (VI)
/OUT1: J2.2, U1.1
/OUT2: J2.3, U1.7
GND: C1.2, C2.2, C3.1, C4.1, D2.2 (A), J2.4, R2.2, R4.2, R6.2, U1.4 (V-), U2.2 (GND)
unnamed: D1.2 (A), D2.1 (K), R1.2, R2.1, U1.2 (-), U1.5 (+)
unnamed: R3.1, R4.1, U1.3 (+)
unnamed: R5.1, R6.1, U1.6 (-)

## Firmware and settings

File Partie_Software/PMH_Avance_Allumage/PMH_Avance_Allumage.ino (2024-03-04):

#include <Arduino.h>
#include <Wire.h> // Bibliothèque I2C
#include <math.h>

// Paramètres de sortie
#define Gain_Out1 1  // -> Régime Moteur : 1V => 1000 tr/min
#define Gain_Out2 68 // -> Avance Allumage : 68 mV => 1° (pour aller de 0 à 60°)
#define Gain_Out3 1  // Gain variable de la carte -> 1 paramètre de base 1V pour 1ms
                     //                           -> 0.5 :   1ms => 0.5V
                     //                           -> 0.25 :  1ms => 0.25V
                     //                           -> 2 :     1ms => 2V
#define Gain_Out4 1  // -> Acceleration : 1V pour 1000(tour/min)−2

#define Address_dac 0x48 // Adresse du DAC
#define OUT1 0x30        // Adresse DAC sortie 1
#define OUT2 0x31        // Adresse DAC sortie 2
#define OUT3 0x32        // Adresse DAC sortie 3
#define OUT4 0x33        // Adresse DAC sortie 4

#define IN1 18 // Pin entrée 1
#define IN2 19 // Pin entrée 2
#define IN3 22 // Pin entrée 3
#define IN4 23 // Pin entrée 4

// Drapeau d'interruption
unsigned int IFLAG; // Drapeau indiquant le type d'interruption détectée

// Variables liées au signal PMH (Point Mort Haut)
unsigned int T1_PMH = 0; // Temps du front montant de PMH
unsigned int T2_PMH = 0; // Temps du front descendant de PMH
unsigned int DP_PMH = 0; // Durée de la dent précédente (previous)
unsigned int DC_PMH = 0; // Durée de la dent actuelle (current)
unsigned int FD_1;       // Temps du début de la période PMH
unsigned int FD_2;       // Temps fin de la période PMH
unsigned int N;          // Variable pour le régime moteur (à préciser si elle est utilisée)
unsigned int count = 1;  // Compteur cycle regimes

double PMH = 0;                 // Variable pour le calcul du régime moteur en tr/
unsigned int buffer_regime = 0; // Buffer pour stocker la valeur du régime moteur

// Variables liées à l'allumage
unsigned int T1_AA = 0; // Temps du front descendant de l'allumage
unsigned int TF = 0;    // Temps à préciser (non utilisé dans le code actuel)
double avance = 0;      // Temps d'avance entre le PMH et l'allumage en microsecondes
double rapport = 0;     // Rapport entre le temps d'avance et la période du PMH
double deg = 0;         // Conversion du rapport en degrés
double solus = 0.7;
double buffer_allumage = 0; // Buffer pour stocker la valeur de l'allumage

// Variables liées au temps de conduction
unsigned int T1_TC = 0;             // Temps début signal
unsigned int T2_TC = 0;             // Temps fin signal
unsigned int duree_condu;           // Duree du temps de conduction
unsigned int buffer_conduction = 0; // Buffer pour stocker la valeur du temps de conduction

// Variables liées à l'acceleration
unsigned int acc_count = 0;         // Compteur différences de régime effectué
unsigned int tmp_regime = 0;        // Variables temporaires pour calcul différence regime et temps ecoule
unsigned int tmp_temps = 0;
double tempsEcoule = 0;             // Temps ecoule entre la premier et dernier regime et la différence associé
int diff_regime;
double buffer_accel = 0;            // Buffer pour stocker la valeur de l'acceleration

void ES_Init() // Fonction initialisation PIN
{
  pinMode(IN1, INPUT); // Signal 1
  pinMode(IN2, INPUT); // Signal 2
  pinMode(IN3, INPUT); // Signal 3
  pinMode(IN4, INPUT); // Signal 4

  pinMode(15, OUTPUT);   // LED test fonctionnement SAMD21
  digitalWrite(15, LOW); // Initialisation Led éteinte
}

void DacInit() // Fonction initialisation DAC
{
  pinMode(10, OUTPUT);    // Clear en sortie du DAC
  pinMode(11, OUTPUT);    // Ldac en sortie du DAC
  digitalWrite(10, LOW);  // Clear à 0
  digitalWrite(11, LOW);  // Ldac à 0
  digitalWrite(10, HIGH); // Remise à 0 du DAC
}

void DacWrite(int data, unsigned int channel)
{
  int MSBD, LSBD; // Variable bit de start et stop

  MSBD = (data & 0xFF0) >> 4;           // 8 bits de poids fort
  LSBD = ((data & 0x00F) << 4) & 0x0FF; // 8 bits de poids faible

  Wire.beginTransmission(Address_dac); // Commence la transmission sur l'adresse du DAC
  Wire.write(channel);                 // Commence la transmission sur la sortie
  Wire.write(MSBD);                    // On envoie 8 bits de poids forts
  Wire.write(LSBD);                    // On envoie 8 bits de poids faible
  Wire.endTransmission();              // On termine la transmission
}

void dacWriteBuffer()
{
  DacWrite(buffer_regime, OUT1);     // Ecriture sur la premiere sortie du regime moteur
  DacWrite(buffer_allumage, OUT2);   // Ecriture sur la deuxieme sortie de la valeur de l'avance à l'allumage
  DacWrite(buffer_conduction, OUT3); // Ecriture sur la troisieme sortie de la valeur du temps de conduction
  DacWrite(buffer_accel, OUT4);      // Ecriture sur la quartieme sortie de la valeur de l'accélération
}

void setup() // Fonction Initialisation Microcontrôleur
{
  Wire.begin();           // Démarrage I2C
  Wire.setClock(3400000); // 180000 bauds
  ES_Init();              // Initialisation des ports d'entrée
  DacInit();              // Initialisation des ports d'activation du DAC
  Serial.begin(115200);   // Démarrage de la liaison série

  attachInterrupt(digitalPinToInterrupt(IN2), deuxieme_interrupt, RISING); // Procédure d'interruption entrée 2, Pin 19
  attachInterrupt(digitalPinToInterrupt(IN3), trois_interrupt, RISING);    // Procédure d'interruption entrée 3, Pin 22
}

// Fonction d'interruption pour l'entrée 1
void premier_interrupt()
{
  IFLAG = 1;
}

// Fonction d'interruption pour l'entrée 2
void deuxieme_interrupt()
{
  IFLAG = 2;
}

// Fonction d'interruption pour l'entrée 3
void trois_interrupt()
{
  IFLAG = 3;
}

void loop()
{
  if (IFLAG == 1)
  {

    DP_PMH = DC_PMH; // Sauvegarde de la durée de la dent précédente pour la comparaison

    T1_PMH = micros(); // Enregistrement du temps du front montant actuel

    DC_PMH = T1_PMH - T2_PMH; // Calcul de la durée de la dent actuelle

    T2_PMH = T1_PMH; // Mise à jour du temps du front montant précédent

    // Si la durée de la dent actuelle est plus de deux fois grande que la durée de la dent précédente : On est sur une fausse dent
    if (DC_PMH > DP_PMH * 2)
    {
      if (count == 1) // On calcule le regime moteur sur une periode, on vérifie donc si on en est au premier ou pas
      {
        FD_1 = T1_PMH; // On enregistre le temps de la dent actuel dans une autre variable

        if (acc_count == 2) // De la meme manière on calcule l'acceleration en faisaint la difference entre 2 regime moteur, donc un autre compteur est nécéssaire
        {
          diff_regime = buffer_regime - tmp_regime; // Calcul de la difference de regime

          tempsEcoule = FD_1 - tmp_temps;               // Calcul du temps écoulé (nécessaire pour un calcul d'accélération)
          tempsEcoule = tempsEcoule / (60 * 1000000.0); // Conversion en minutes

          tmp_temps = FD_1;           // Enregistrement du temps actuel pour le calcul suivant
          tmp_regime = buffer_regime; // Enregistrement du regime moteur actuel pour le calcul suivant
          acc_count = 0;              // Remise à 0 du compteur d'accélération
        }
        else
        {
          acc_count++;
        }
        count++;
      }
      else if (count == 2) // Deuxieme tour de boucle, on peut calculer tout les buffer
      {
        FD_2 = T1_PMH;

        // Calcul de la période du PMH et mise à jour du buffer de régime moteur
        PMH = (FD_2 - FD_1);
        buffer_regime = ((60000000 / PMH)) * Gain_Out1;
        buffer_regime = (buffer_regime > 4095) ? 4095 : (buffer_regime < 0) ? 0
                                                                            : buffer_regime;

        // Calcul de l'accélération et mise à jour du buffer d'accélération
        buffer_accel = (((static_cast<double>(diff_regime) / tempsEcoule) / 100) + 1000) * Gain_Out4;
        buffer_accel = (buffer_accel > 4095) ? 4095 : (buffer_accel < 0) ? 0
                                                                         : buffer_accel;

        FD_1 = T1_PMH;
        count = 1;

        detachInterrupt(IN1); // Arret de l'interruption, tout les calculs ont étés faits

        // Mise en route des autres interruptions
        attachInterrupt(digitalPinToInterrupt(IN2), deuxieme_interrupt, RISING); // Procédure d'interruption entrée 2, Pin 19
        attachInterrupt(digitalPinToInterrupt(IN3), trois_interrupt, RISING);    // Procédure d'interruption entrée 3, Pin 22
      }
    }
    IFLAG = 0;
  }
  // Section d'interruption pour le signal 2
  if (IFLAG == 2)
  {
    // Enregistrement du temps actuel
    T1_AA = micros();

    // Calcul de l'avance en microsecondes
    avance = T1_AA - FD_2;

    // Calcul du rapport entre la durée du PMH et l'avance
    rapport = PMH / (avance);

    // Calcul de l'angle d'allumage en degrés
    deg = (((rapport * 360) - 240) / 2) * solus; // == 70

    // Conversion de l'angle d'allumage en tension pour le DAC
    buffer_allumage = (deg)*Gain_Out2;
    buffer_allumage = (buffer_allumage > 4095) ? 4095 : (buffer_allumage < 0) ? 0
                                                                              : buffer_allumage;

    // Détachement de l'interruption pour le signal 2
    detachInterrupt(IN2);

    // Écriture des valeurs dans le DAC
    dacWriteBuffer();

    // Réattachement de l'interruption pour le signal 1 sur le front descendant
    attachInterrupt(digitalPinToInterrupt(IN1), premier_interrupt, FALLING); // Procédure d'interruption entrée 2, Pin 18

    // Réinitialisation du drapeau d'interruption
    IFLAG = 0;
  }

  // Section d'interruption pour le signal 3
  if (IFLAG == 3)
  {
    // Enregistrement du temps actuel
    T1_TC = micros();

    // Attente de la fin du signal pour éviter une mesure erronée
    while (digitalRead(IN3))
      ;

    // Enregistrement du temps de fin du signal
    T2_TC = micros();

    // Calcul de la durée de conduction en microsecondes
    duree_condu = (T2_TC - T1_TC) * Gain_Out3;

    // Conversion de la durée de conduction en tension pour le DAC
    buffer_conduction = (duree_condu > 4095) ? 4095 : (duree_condu < 0) ? 0
                                                                        : duree_condu;

    // Détachement de l'interruption pour le signal 2
    detachInterrupt(IN2);

    // Écriture des valeurs dans le DAC
    dacWriteBuffer();

    // Réattachement de l'interruption pour le signal 1 sur le front descendant
    attachInterrupt(digitalPinToInterrupt(IN1), premier_interrupt, FALLING);

    // Réinitialisation du drapeau d'interruption
    IFLAG = 0;
  }
}

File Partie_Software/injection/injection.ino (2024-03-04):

#include <Arduino.h>  //Bibliothèque Arduino
#include <Wire.h> //Bibliothèque I2C

#define Gain 0.5  // Gain variable de la carte -> 1 paramètre de base 1V pour 1ms 
                  //                           -> 0.5 :   1ms => 0.5V
                  //                           -> 0.25 :  1ms => 0.25V
                  //                           -> 2 :     1ms => 2V

#define Adress_dac 0x48 // Adresse du DAC 
#define INJ1 0x30 // Adresse DAC sorti 1
#define INJ2 0x31 // Adresse DAC sorti 2
#define INJ3 0x32 // Adresse DAC sorti 3
#define INJ4 0x33 // Adresse DAC sorti 4

#define IN1 18    // Pin entré 1
#define IN2 19    // Pin entré 2
#define IN3 22    // Pin entré 3
#define IN4 23    // Pin entré 4

unsigned int FRONT;   // Variable pour lancer la transmission des données au DAC
unsigned int INJ,IN;  // Variable pour faire correspondre la sortie
unsigned long int TI; // Temps initial
unsigned long int TF;   // Temps final

void ES_Init()  // Fonction initialisation PIN
{
  pinMode(IN1, INPUT);       // Signal 1
  pinMode(IN2, INPUT);       // Signal 2
  pinMode(IN3, INPUT);       // Signal 3
  pinMode(IN4, INPUT);       // Signal 4

  pinMode(15, OUTPUT);      // LED test fonctionnement SAMD21
  digitalWrite(15,LOW);     // Initialisation Led éteinte
}

void DacInit()  // Fonction initialisation DAC
{
  pinMode(10, OUTPUT);      // Clear en sortie du DAC
  pinMode(11, OUTPUT);      // Ldac en sortie du DAC
  digitalWrite(10, LOW);    // Clear à 0
  digitalWrite(11, LOW);    // Ldac à 0
  digitalWrite(10, HIGH);   // Remise à 0 du DAC
}

void DacWrite (unsigned int data, unsigned int channel)
{
  int MSBD, LSBD;       // Variable bit de start et stop

  MSBD = (data & 0xFF0) >> 4;           // 8 bits de poids fort
  LSBD = ((data & 0x00F) << 4 ) & 0x0FF;// 8 bits de poids faible

  Wire.beginTransmission(Adress_dac);   // Commence la transmission sur l'adresse du DAC
  Wire.write(channel);                  // Commence la transmission sur la sortie
  Wire.write(MSBD);                     // On envoie 8 bits de poids forts
  Wire.write(LSBD);                     // On envoie 8 bits de poids faible
  Wire.endTransmission();               // On termine la transmission
}


void chrono1()  // Fonction d’interruption Pin 18 ( entré 1 )
{
  FRONT = 1;  // Drapeau de gestion de transmission à 1
  INJ = INJ1;   // Drapeau de gestion de sortie à INJ1 ( address 0x30 )
  IN=IN1;       // Drapeau de gestion de lecture de la pin
}

void chrono2()  // Fonction d'interruption Pin 19 ( entré 2 )
{
  FRONT = 1;  // Drapeau de gestion de transmission à 1
  INJ = INJ2;   // Drapeau de gestion de sortie à INJ2 ( address 0x31 )
  IN=IN2;       // Drapeau de gestion de lecture de la pin
}

void chrono3()  // Fonction d'interruption Pin 22 ( entré 3 )
{
  FRONT = 1;  // Drapeau de gestion de transmission à 1
  INJ = INJ3;   // Drapeau de gestion de sortie à INJ3 ( address 0x32 )
  IN=IN3;       // Drapeau de gestion de lecture de la pin
}

void chrono4()  // Fonction d'interruption Pin 23 ( entré 4 )
{
  FRONT = 1;  // Drapeau de gestion de transmission à 1
  INJ = INJ4;   // Drapeau de gestion de sortie à INJ4 ( address 0x33 )
  IN=IN4;       // Drapeau de gestion de lecture de la pin
}

void setup()  // Fonction Initialisation Microcontroleur 
{
  Wire.begin(); // Démarrage I2C
  Wire.setClock(3400000); // 180000 bauds
  ES_Init();  // Initialisation des ports d'entrée
  DacInit();    // Initialisation des ports d'activation du DAC
  Serial.begin(9600); // Démarrage de la liaison série 

  attachInterrupt(digitalPinToInterrupt(18), chrono1, FALLING); // procédure d'interruption entré 1, Pin 18
  attachInterrupt(digitalPinToInterrupt(19), chrono2, FALLING); // procédure d'interruption entré 2, Pin 19
  attachInterrupt(digitalPinToInterrupt(22), chrono3, FALLING); // procédure d'interruption entré 3, Pin 22  
  attachInterrupt(digitalPinToInterrupt(23), chrono4, FALLING); // procédure d'interruption entré 4, Pin 23  
}

void loop()    // Fonction principal
{
  if (FRONT == 1)     // Si un fonction d’interruption est activé
  {
    TI = micros();    // TI = valeur du compteur au temps présent
    while(digitalRead(IN)==0);  // Tant qu’on lit un état bas sur une Pin
    TF = micros();    // TF = valeur du compteur au temps présent
    DacWrite((TF-TI)*Gain, INJ);  // Fonction d’écriture du DAC
    FRONT = 0;      // Remettre le drapeau à un pour bien transmettre d’autre valeur
  }
}
